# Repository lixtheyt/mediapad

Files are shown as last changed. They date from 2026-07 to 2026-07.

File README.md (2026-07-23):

<!-- HELYX_STATUS_START -->

<!-- HELYX_STATUS_END -->

# Mediapad

Mediapad is an 8 key hackpad with a rotary encoder, an OLED Display. It also has 20 SK6812 MINI-E LEDs, and uses QMK firmware.

## Features:
- 128x32 OLED Display
- EC11 Rotary encode
- 20 SK6812 MINI-E LEDs. We gotta make somethin' for party nah??
- cool designed case

## CAD Model:
Everything fits together using 6 M3 Bolts and heatset inserts. 4 for the case and 2 for the PCB.

It has 4 separate printed pieces.
3 are parts of the case and 1 is a spacer for the glow...

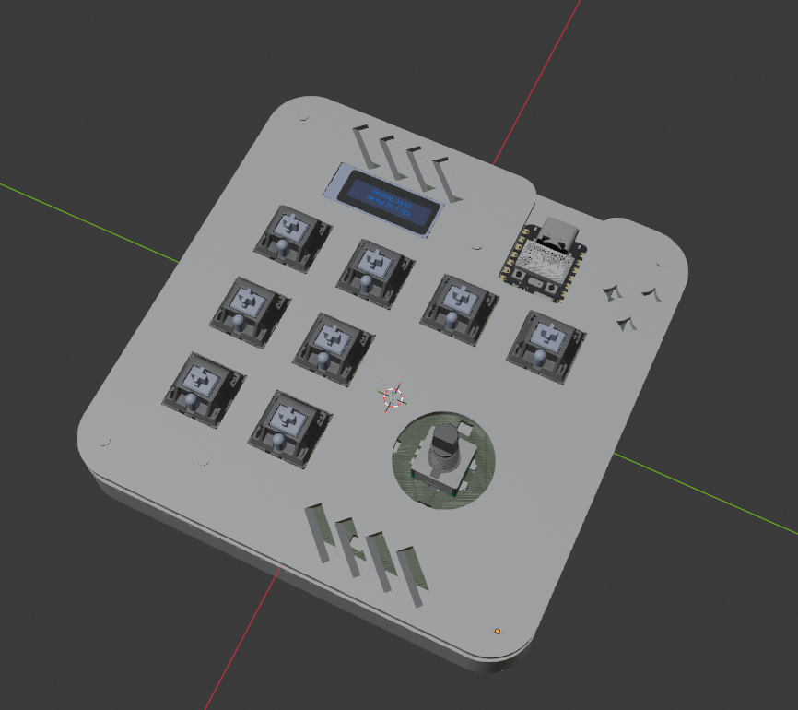
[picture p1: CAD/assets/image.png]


## PCB
I made my PCB inside KiCad.
Libraries I used were originally from the Hackpad website but I also used some that I had found on [grabcad](https://grabcad.com/library)

### Schematic
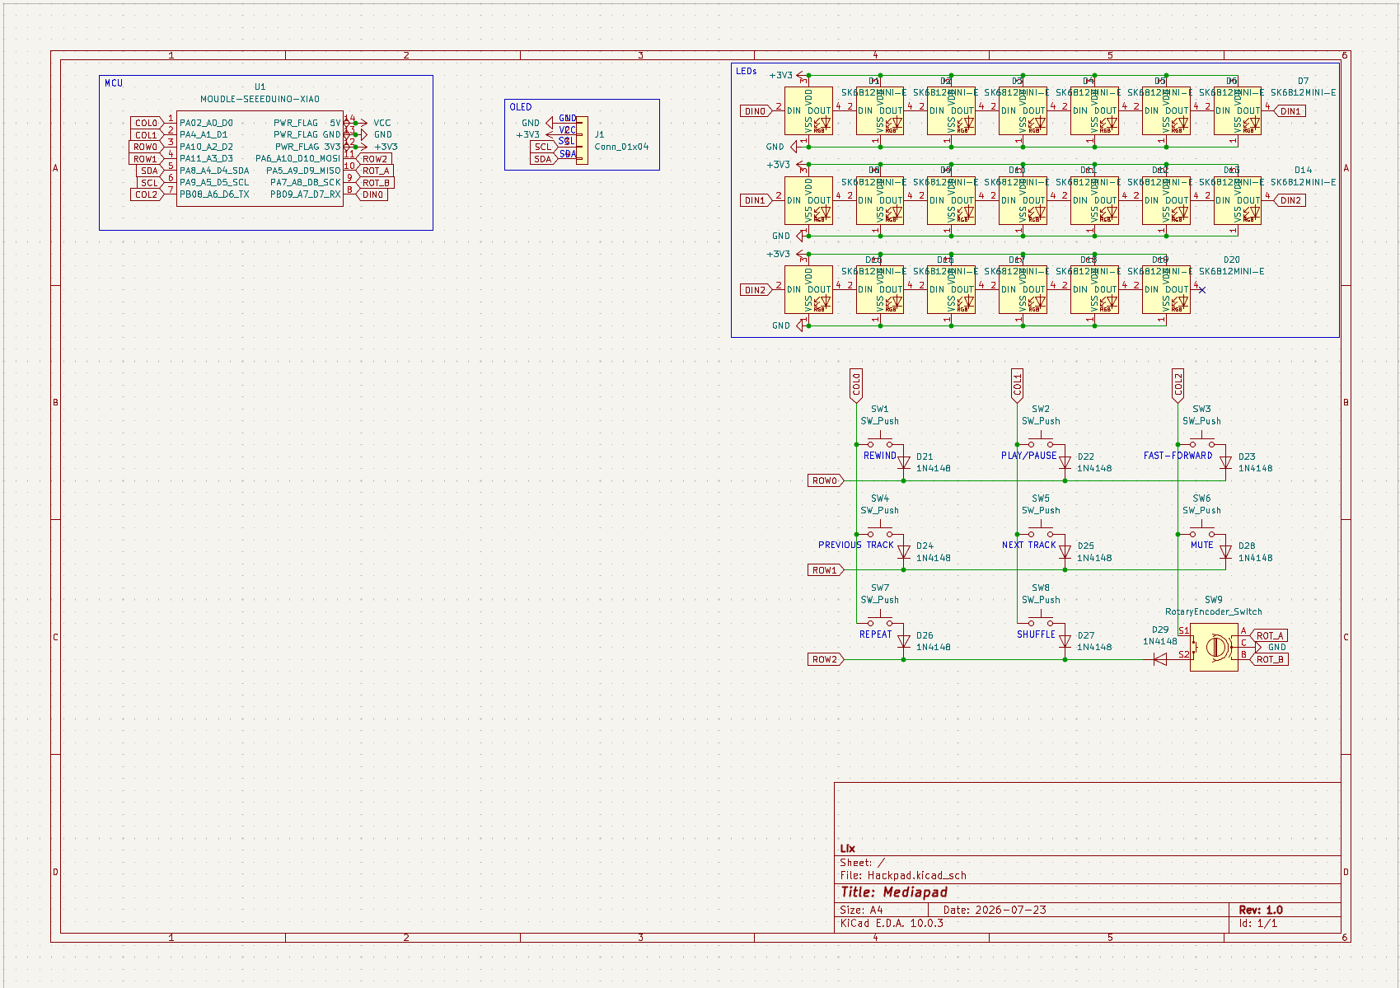
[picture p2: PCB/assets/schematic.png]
Schematic


### PCB
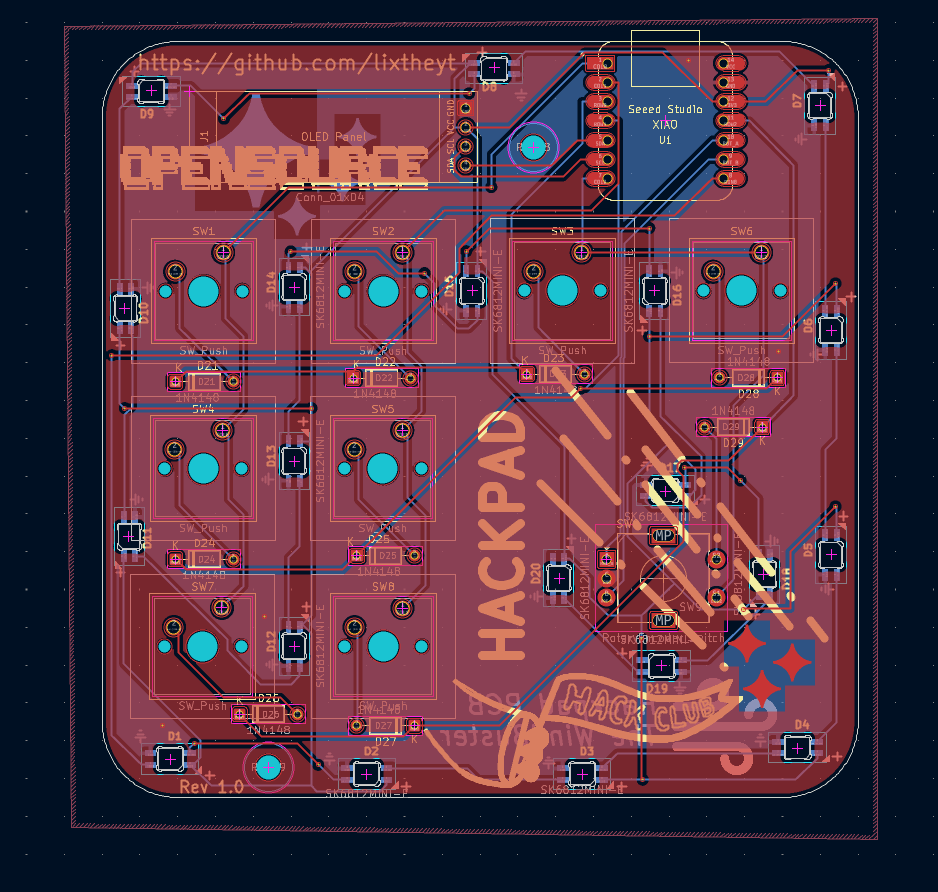
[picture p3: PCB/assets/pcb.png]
PCB


## Firmware Overview
This hackpad uses [QMK](https://qmk.fm/) firmware for everything.

### Rotary encoder
Tapping the encoder cycles through five modes; turning it then performs that
mode's action. The mode name flashes on the OLED each time you tap.

1. **Volume** — volume up / down
2. **Track skip** — next / previous track
3. **Arrows** — arrow up / down
4. **Scroll** — mouse wheel up / down
5. **Zoom** — zoom in / out (Ctrl +/-)

### RGB
The lighting is separate from the encoder cycle and is opened with the two middle
keys, so it does not eat one of the modes above:

- **RGB Scene** — 6 premade animations: Pinwheel, Vortex (color swirl around
  the board), Rainbow wave, Chevron, Splash and Raindrops. On this layer the
  encoder switches scene or sets brightness.
- **RGB Custom** — mix your own color (red / green / blue / brightness, each dialled
  in with the encoder) and pick from ten effects, including reactive ones that
  light up outward from the key you press.

### OLED
Shows the currently playing track — title, artist and a progress bar — streamed
from the companion app below, plus the name of each mode when you switch.
When messing with RGB lighting it also shows current informations that are helpful for setting it correctly.

## BOM:

- 8x Cherry MX Switches
- 8x Keycaps
- 6x M3x5x4 Heatset inserts
- 6x M3x16mm Screws
- 8x 1N4148 DO-35 Diodes
- 20x SK6812 MINI-E LEDs
- 1x 0.91" 128x32 OLED Display
- 1x EC11 Rotary Encoder
- 1x XIAO RP2040
- 1x Case (1x bottom case, 1x middle case, 1x top case)
- 6x Spacers (printed part)

## Companion app (now playing on the OLED)

`Companion/mediapad_tray.exe` is a portable application made in Python that feeds Mediapad with the latest
information about current played media on your computer. Without it the OLED just shows "Hackpad".

As I have mentioned... it is a portable application. That means you don't have to install anything.
Just open, mess with it in the tray (where background applications are located) and make sure to enable
the setting that allows it to open on start up of your computer, so you don't have to turn it on manually
every time you turn on your computer. If you've got no idea where the tray with the background applications
is located then please, google it.

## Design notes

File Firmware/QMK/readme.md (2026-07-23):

# mediapad

mediapad

A 9-key media macropad: 8 Cherry MX switches plus an EC11 rotary encoder with a
push switch, a 128x32 SSD1306 OLED and 20 SK6812 MINI-E underglow LEDs, driven
by a Seeed XIAO RP2040.

* Keyboard Maintainer: [Lix](https://github.com/lixtheyt)
* Hardware Supported: mediapad PCB + XIAO RP2040
* Hardware Availability: https://github.com/lixtheyt/mediapad

Make example for this keyboard (after setting up your build environment):

    make mediapad:lixtheyt

Flashing example for this keyboard:

    make mediapad:lixtheyt:flash

See the [build environment setup](https://docs.qmk.fm/#/getting_started_build_tools) and the [make instructions](https://docs.qmk.fm/#/getting_started_make_guide) for more information. Brand new to QMK? Start with our [Complete Newbs Guide](https://docs.qmk.fm/#/newbs).

## Bootloader

Enter the bootloader in 3 ways:

* **Bootmagic reset**: Hold down the top left key (rewind) and plug in the keyboard
* **Physical reset button**: Double-tap the reset button on the XIAO RP2040
* **Key combo**: Hold rewind + fast-forward + mute for 5 seconds

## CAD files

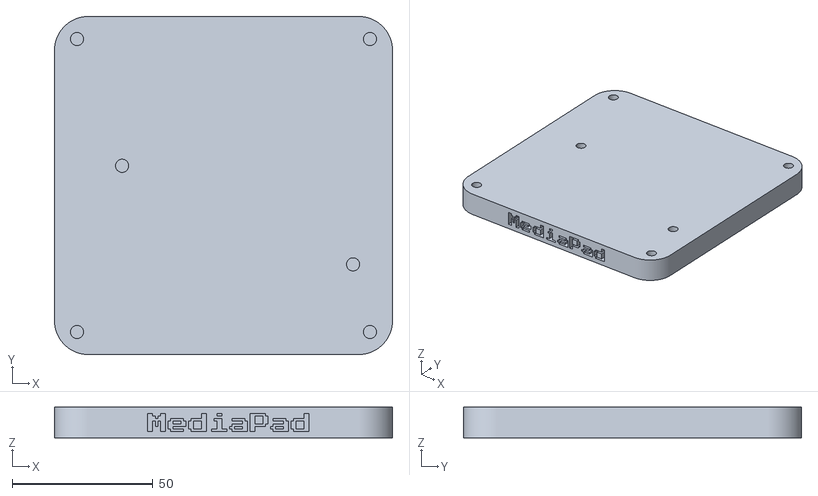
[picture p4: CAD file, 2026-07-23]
Production/bottomCase.stl
120.0 x 120.0 x 11.0

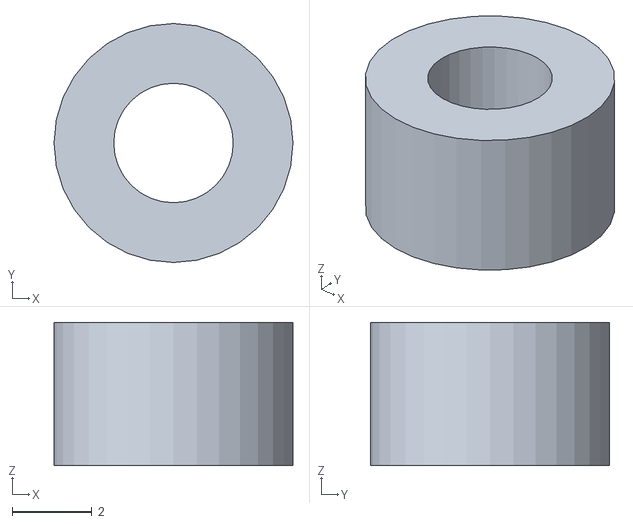
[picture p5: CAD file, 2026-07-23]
Production/spacer.stl
6.00 x 6.00 x 3.60

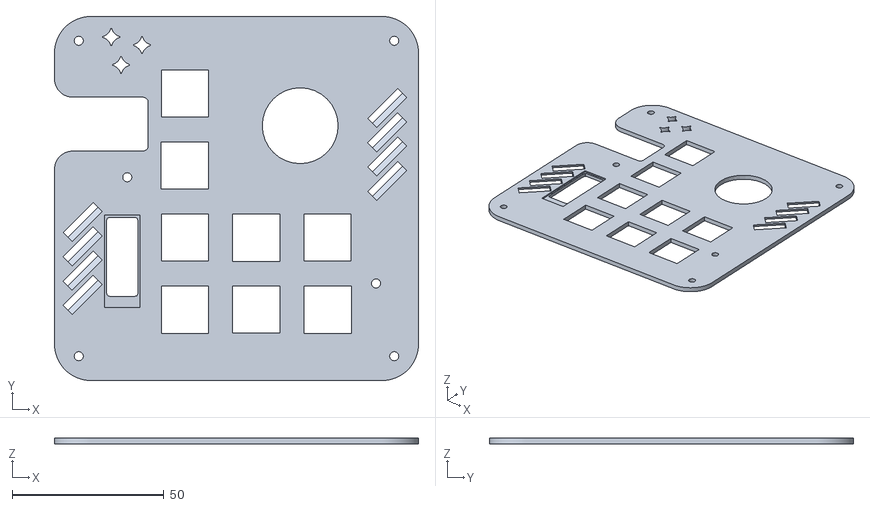
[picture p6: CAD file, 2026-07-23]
Production/topCase.stl
120.0 x 120.0 x 2.00

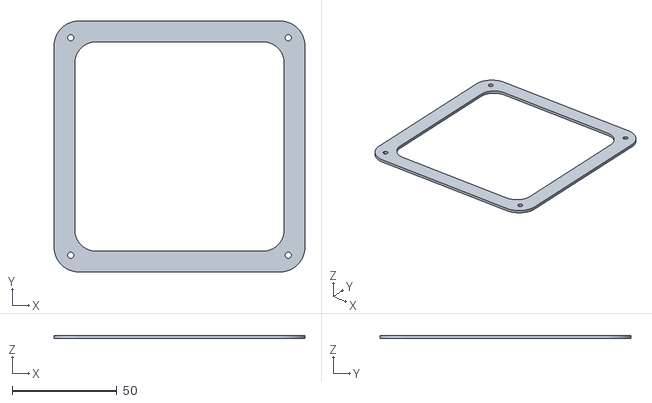
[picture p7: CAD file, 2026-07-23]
Production/middleCase.stl
120.0 x 120.0 x 1.60

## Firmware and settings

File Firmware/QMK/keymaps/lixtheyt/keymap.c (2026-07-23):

// Copyright 2026 Lix
// SPDX-License-Identifier: GPL-2.0-or-later

#include QMK_KEYBOARD_H
#include <string.h>
#include <stdio.h>

enum custom_keycodes {
    KC_SHUFFLE = SAFE_RANGE,
    KC_REPEAT,
    CYCLE_LAYER,
    RGB_MODE_CUSTOM,
    RGB_MODE_SCENE,
    RGB_SEL_R,
    RGB_SEL_G,
    RGB_SEL_B,
    RGB_SEL_VAL,
    RGB_SEL_SCENE,
    RGB_FX_NEXT,
    RGB_FX_PREV
};

#define NUM_FUNC_LAYERS 5
#define LAYER_RGB_CUSTOM 5
#define LAYER_RGB_SCENE 6
#define RGB_STEP 8

/* Must match rgb_matrix.max_brightness in keyboard.json. 20 SK6812s at full
 * white would pull well over an amp, so brightness is capped here too and the
 * OLED reports the same number the driver actually uses. */
#define RGB_VAL_MAX 150

static uint8_t rgb_r = 255, rgb_g = 255, rgb_b = 255;
static uint8_t rgb_val = RGB_VAL_MAX;

static uint32_t oled_message_timer = 0;
#define OLED_MESSAGE_DURATION 3000

static const char *system_msg = NULL;
static uint32_t system_msg_timer = 0;
#define SYSTEM_MSG_DURATION 2000

static bool held[3][3] = {0};
static bool combo_fired = false;

#define HOLD_TIME_LONG  5000
#define HOLD_TIME_SHORT 2000

typedef enum { COMBO_NONE, COMBO_BOOTLOADER, COMBO_EEPROM, COMBO_REBOOT, COMBO_DEBUG } combo_id_t;
static combo_id_t active_combo = COMBO_NONE;
static uint32_t combo_start_timer = 0;

static bool is_held(uint8_t r, uint8_t c) { return held[r][c]; }

static combo_id_t detect_combo(void) {
    bool rewind = is_held(0,0), ff = is_held(0,2), mute = is_held(1,2);
    bool repeat = is_held(2,0), shuffle = is_held(2,1);

    if (rewind && ff && mute)   return COMBO_BOOTLOADER;
    if (repeat && shuffle && mute) return COMBO_EEPROM;
    if (rewind && ff)           return COMBO_REBOOT;
    if (repeat && shuffle)      return COMBO_DEBUG;
    return COMBO_NONE;
}

static void update_hidden_combos(void) {
    combo_id_t detected = detect_combo();

    if (detected == COMBO_NONE) {
        active_combo = COMBO_NONE;
        combo_fired = false;
        return;
    }

    if (detected != active_combo) {
        active_combo = detected;
        combo_start_timer = timer_read32();
        combo_fired = false;
        return;
    }

    if (combo_fired) return;

    uint32_t needed = (detected == COMBO_REBOOT) ? HOLD_TIME_SHORT : HOLD_TIME_LONG;
    if (timer_elapsed32(combo_start_timer) < needed) return;

    combo_fired = true;
    switch (detected) {
        case COMBO_BOOTLOADER:
            oled_clear();
            oled_write_ln("BOOTLOADER", false);
            oled_render();
            wait_ms(300);
            bootloader_jump();
            break;
        case COMBO_EEPROM:
            eeconfig_init();
            system_msg = "EEPROM CLEARED";
            system_msg_timer = timer_read32();
            break;
        case COMBO_REBOOT:
            oled_clear();
            oled_write_ln("REBOOTING", false);
            oled_render();
            wait_ms(300);
            soft_reset_keyboard();
            break;
        case COMBO_DEBUG:
            debug_enable ^= 1;
            system_msg = debug_enable ? "DEBUG ON" : "DEBUG OFF";
            system_msg_timer = timer_read32();
            break;
        case COMBO_NONE:
            break;
    }
}

#define NOWPLAYING_STALE_MS 4000

static char np_title[13]  = {0};
static char np_artist[12] = {0};
static uint16_t np_pos_sec = 0;
static uint16_t np_dur_sec = 0;
static bool np_playing = false;
static uint32_t np_last_update = 0;
static bool np_has_data = false;

void raw_hid_receive(uint8_t *data, uint8_t length) {
    if (length < 32) return;
    if (data[0] != 0x01) return;

    np_playing = data[1] != 0;
    np_pos_sec = (uint16_t)data[2] | ((uint16_t)data[3] << 8);
    np_dur_sec = (uint16_t)data[4] | ((uint16_t)data[5] << 8);

    uint8_t title_len = data[6];
    if (title_len > 12) title_len = 12;
    memset(np_title, 0, sizeof(np_title));
    memcpy(np_title, &data[7], title_len);

    uint8_t artist_len = data[19];
    if (artist_len > 11) artist_len = 11;
    memset(np_artist, 0, sizeof(np_artist));
    memcpy(np_artist, &data[20], artist_len);

    np_has_data = true;
    np_last_update = timer_read32();
}

static bool nowplaying_is_stale(void) {
    if (!np_has_data) return true;
    return timer_elapsed32(np_last_update) > NOWPLAYING_STALE_MS;
}

/* What the encoder is currently pointed at. Picking a target is a separate
 * press from turning it, so one encoder can drive every RGB parameter. */
enum rgb_channel { CH_NONE, CH_RED, CH_GREEN, CH_BLUE, CH_BRIGHTNESS, CH_SCENE };
static enum rgb_channel active_channel = CH_NONE;

typedef struct { uint8_t mode; const char *name; } rgb_preset_t;

/* Scenes are whole animations, the sort of thing a normal keyboard ships with.
 * Splash also reacts to keypresses, spreading out from the key you hit. */
static const rgb_preset_t rgb_scenes[] = {
    {RGB_MATRIX_CYCLE_PINWHEEL,         "Pinwheel"},
    {RGB_MATRIX_CYCLE_SPIRAL,           "Vortex"},
    {RGB_MATRIX_CYCLE_LEFT_RIGHT,       "Rainbow wave"},
    {RGB_MATRIX_RAINBOW_MOVING_CHEVRON, "Chevron"},
    {RGB_MATRIX_SPLASH,                 "Splash"},
    {RGB_MATRIX_JELLYBEAN_RAINDROPS,    "Raindrops"},
};
#define NUM_SCENES (sizeof(rgb_scenes) / sizeof(rgb_scenes[0]))
static uint8_t scene_index = 0;

/* Custom effects all honour the hue/sat dialled in with RGB_SEL_R/G/B, so the
 * colour you mix is the colour that comes out. */
static const rgb_preset_t rgb_custom_fx[] = {
    {RGB_MATRIX_SOLID_COLOR,           "Solid"},
    {RGB_MATRIX_BREATHING,             "Breathing"},
    {RGB_MATRIX_BAND_VAL,              "Band"},
    {RGB_MATRIX_BAND_PINWHEEL_VAL,     "Band pinwheel"},
    {RGB_MATRIX_BAND_SPIRAL_VAL,       "Band spiral"},
    {RGB_MATRIX_SOLID_REACTIVE_SIMPLE, "React simple"},
    {RGB_MATRIX_SOLID_REACTIVE,        "React hue"},
    {RGB_MATRIX_SOLID_REACTIVE_WIDE,   "React wide"},
    {RGB_MATRIX_SOLID_REACTIVE_CROSS,  "React cross"},
    {RGB_MATRIX_SOLID_SPLASH,          "Splash solid"},
};
#define NUM_CUSTOM_FX (sizeof(rgb_custom_fx) / sizeof(rgb_custom_fx[0]))
static uint8_t custom_fx_index = 0;

static inline uint8_t clamp_add(uint8_t val, int16_t delta) {
    int16_t r = (int16_t)val + delta;
    if (r < 0) return 0;
    if (r > 255) return 255;
    return (uint8_t)r;
}

static inline uint8_t clamp_val(uint8_t val, int16_t delta) {
    int16_t r = (int16_t)val + delta;
    if (r < 0) return 0;
    if (r > RGB_VAL_MAX) return RGB_VAL_MAX;
    return (uint8_t)r;
}
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

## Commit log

2026-07-23 Added main content
    [Hackpad.kicad_sch, bottomCase.stl, middleCase.stl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]
2026-07-23 Modified Schematics
    [Hackpad.kicad_sch]
2026-07-23 Updated directory structure and added support files for PCB
